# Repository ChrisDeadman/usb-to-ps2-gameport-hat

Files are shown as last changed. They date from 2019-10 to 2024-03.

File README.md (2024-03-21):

Usb => PS/2 & Gameport HAT v1.4
===============================

Author: ChrisDeadman

Convert USB devices to PS/2 & Gameport devices with the power of Arduino 🙂

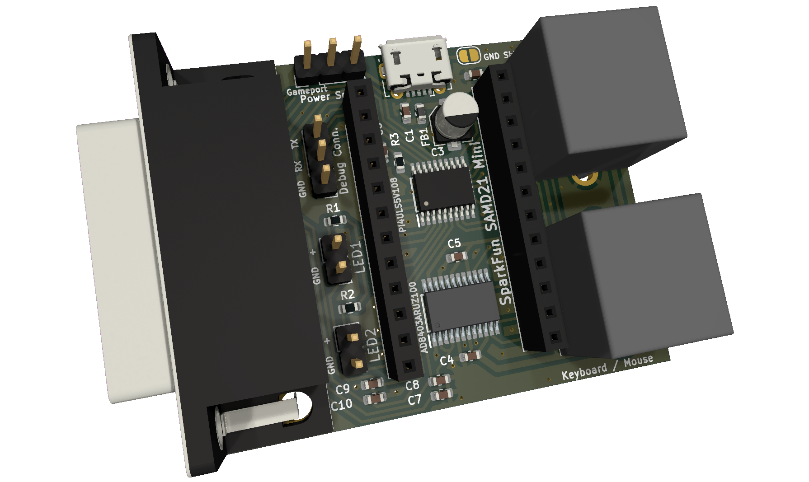
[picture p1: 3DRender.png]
3D render


## Supported input devices
* HID Mouse
* HID Keyboard
* HID Mouse / Keyboard Combo
* HID Joystick / Gamepad\*
* Xbox 360 Controller\*\*

\* *Descriptor parsing is a work in progress and may not work for all devices.*  
\*\* *Currently, only the Xbox 360 Wireless Receiver is supported.*

## Outputs
* PS/2 Mouse\* port
* PS/2 Keyboard\*\* / Mouse combined port
* Gameport

\* *All types are supported, including IntelliMouse (5 Buttons + Scroll wheel).*  
\*\* *Scancode Set 2*

## Supported Arduino Boards
* [SparkFun SAMD21 Mini Breakout](https://www.sparkfun.com/products/13664)\*

\* *Other ATSAMD21G18 boards should also work well, provided they have the same pinout.*

## Usage

* Power the board using a USB cable and set the **Power select** jumper to **USB**.  
  **Alternative:** Set **Power select** jumper to **Gameport**. Be aware that the current is limited depending on the host machine.

* Use a USB OTG cable to connect your USB device to the Arduino.  
  **Recommendation:** Connect a USB hub to the Arduino if you want to use multiple USB devices.

## LEDs

* **LED1** is **ON** if the host inhibits any PS/2 port.
* **LED1** is **FLASHING** if data transfer occurs over any PS/2 port.
* **LED2** indicates **Joy Button** press or the highest **Axis Value**.

## Input Mappings

### USB -> Gameport

This is how USB Joysticks / Gamepads are mapped to the Gameport:

| Joystick 1 | Joystick 2 | Gameport |
|:---|:---|:---|
| X-Axis 1 / D-Pad | - | X-Axis 1 |
| Y-Axis 1 / D-Pad | - | Y-Axis 1 |
| X-Axis 2 | X-Axis 1 / D-Pad  | X-Axis 2 |
| Y-Axis 2 | Y-Axis 2 / D-Pad  | Y-Axis 2 |
| Button 1 / A / R2 | - | Button 1 |
| Button 2 / B / L2 | - | Button 2 |
| Button 3 / X / Select | Button 1 / A / R2 | Button 3 |
| Button 4 / Y / Start  | Button 2 / B / L2 | Button 4 |

### Emulation Mode Mappings

Consult the table below to understand the mapping between various device inputs when an emulation mode is enabled:

| Keyboard | Mouse | Joystick | Gameport |
|:---|:---|:---|:---|
| Left / Right Arrow  | X-Axis | X-Axis 1 / D-Pad | X-Axis 1 |
| Up / Down Arrow | Y-Axis | Y-Axis 1 / D-Pad | Y-Axis 1 |
| A / D | - | X-Axis 2 | X-Axis 2 |
| W / S | Scroll wheel | Y-Axis 2 | Y-Axis 2 |
| L-Ctrl / R-Ctrl | Button 1 | Button 1 / A | Button 1 |
| Space / R-Shift | Button 2 | Button 2 / B | Button 2 |
| L-Alt / CapsLock | Button 3 | Button 3 / X | Button 3 |
| L-Shift | Button 4 | Button 4 / Y | Button 4 |
| Period | Button 5 | Button 5 / R1 | - |
| Comma | - | Button 6 / L1 | - |
| Up Arrow | - | Button 7 / R2 | - |
| Down Arrow | - | Button 8 / L2 | - |
| Escape | - | Button 9 / SELECT | - |
| Tab | - | Button 10 / START | - |

#### Here are a few examples:

* **Joystick -> Keyboard** Emulation Mode:  
  Moving the joystick along X-Axis 1 *(or D-Pad left and right)* acts as if you pressed the Left / Right Arrow keys on the keyboard.

* **Joystick -> Mouse** Emulation Mode:  
  Moving the joystick along X-Axis 1 *(or D-Pad left and right)* move the mouse cursor along the X-Axis.

* **Keyboard -> Joystick** Emulation Mode:  
  If **L-CTRL** or **R-CTRL** is pressed, it acts as if you pressed Button 1 on the joystick.

* **Keyboard -> Mouse** Emulation Mode:  
  The Left / Right Arrow keys on your keyboard move the mouse cursor along the X-Axis.

* **Mouse -> Joystick** Emulation Mode:  
  Moving the mouse left and right corresponds to moving the joystick along the X-Axis 1.

## Setup Mode

Enter this mode to enable special features. Note that those settings are reset to default when the device is reset.

#### Feedback

* **LED1** blink count indicates the current setting.
* **LED2** blink count indicates the value of the current setting, blinks only in edit mode.
* Keyboard LEDs will also blink accordingly (**LED1**=**CapsLock**, **LED2**=**NumLock** and **ScrollLock**).
* LEDs of supported controllers (e.g. Xbox 360) will also blink accordingly.

#### Settings

| Setting | LED1 Blinks | Values / LED2 Blinks | Default |
|:---|:---:|:---|:---:|
| Emulation Mode | 1 | **OFF** | **OFF** |
| | | **1**  Joystick -> Keyboard | |
| | | **2**  Joystick -> Mouse | |
| | | **3**  Keyboard -> Joystick | |
| | | **4**  Keyboard -> Mouse | |
| | | **5**  Mouse -> Joystick | |
| Swap joy axis 3 and 4 | 2 | **ON** / **OFF** | **OFF** |
| Mouse Emu Speed | 3 | **1 <= n <= 255** | **2** |

#### Key bindings

| Keyboard | Joystick / Gamepad | Function |
|:---|:---|:---|
| CTRL+SHIFT+WIN  | Button 5 / R1 + Button 6 / L1 | Hold for ~1s to enter/exit setup mode |
| Return | Button 1 / A | Edit setting / exit edit mode |
| Right Arrow | X-Axis 1 / D-PAD Right | Next setting / increase value (edit mode) |
| Left Arrow | X-Axis 1 / D-PAD Left | Prev. setting / decrease value (edit mode) |
| ESC | Button 9 / SELECT | Apply Default Settings and exit setup mode |
| F1 | - | Set Emulation Mode #1 and exit setup mode |
| F2 | - | Set Emulation Mode #2 and exit setup mode |
| F3 | - | Set Emulation Mode #3 and exit setup mode |
| F4 | - | Set Emulation Mode #4 and exit setup mode |
| F5 | - | Set Emulation Mode #5 and exit setup mode |
| F6 | - | Toggle Swap joy axis 3 and 4 and exit setup mode  |
| F7 | - | Decrease Mouse Emu Speed and exit setup mode |
| F8 | - | Increase Mouse Emu Speed and exit setup mode |

## Flashing the firmware

* Install drivers for you serial adapter
* Connect the **SAMD21 Mini Breakout** to your computer  
*(either via USB OTG cable or via the Debug Conn. pins using a USB<->Serial converter)*
* Double-Tap the reset button on the board to enter bootloader mode

### Automatically

* [Download and run latest firmware_flash.bat](https://github.com/ChrisDeadman/usb-to-ps2-gameport-hat/releases/latest)

### Manually

* [Download latest firmware.bin](https://github.com/ChrisDeadman/usb-to-ps2-gameport-hat/releases/latest)
* [Download Bossa](https://www.shumatech.com/web/products/bossa)
* Flash with `bossac --port=/dev/ttyUSB0 -U -i --offset=0x2000 -e -w firmware.bin -R`

*Ensure you change `--port` to match your system's actual port. The example provided is for Linux systems.*

## Developer Notes

* Diagnostic information is available via **Debug Conn. @ 115200 8N1**  
  *Sending any character returns sent/received data and device status.*

* Enable USB Debugging in `USB.h` *(in USB_Host_Library_SAMD)* by uncommenting `#define DEBUG_USB_HOST 1` and setting `#define USB_HOST_SERIAL` to `SERIAL_PORT_HARDWARE`.

* You can change pins in `include/Config.h`.

* You can add support for additional USB devices by implementing a `JoystickDriverMapper` and adding it to `joy_mappers` in `main.cpp`.

Schematic
=========

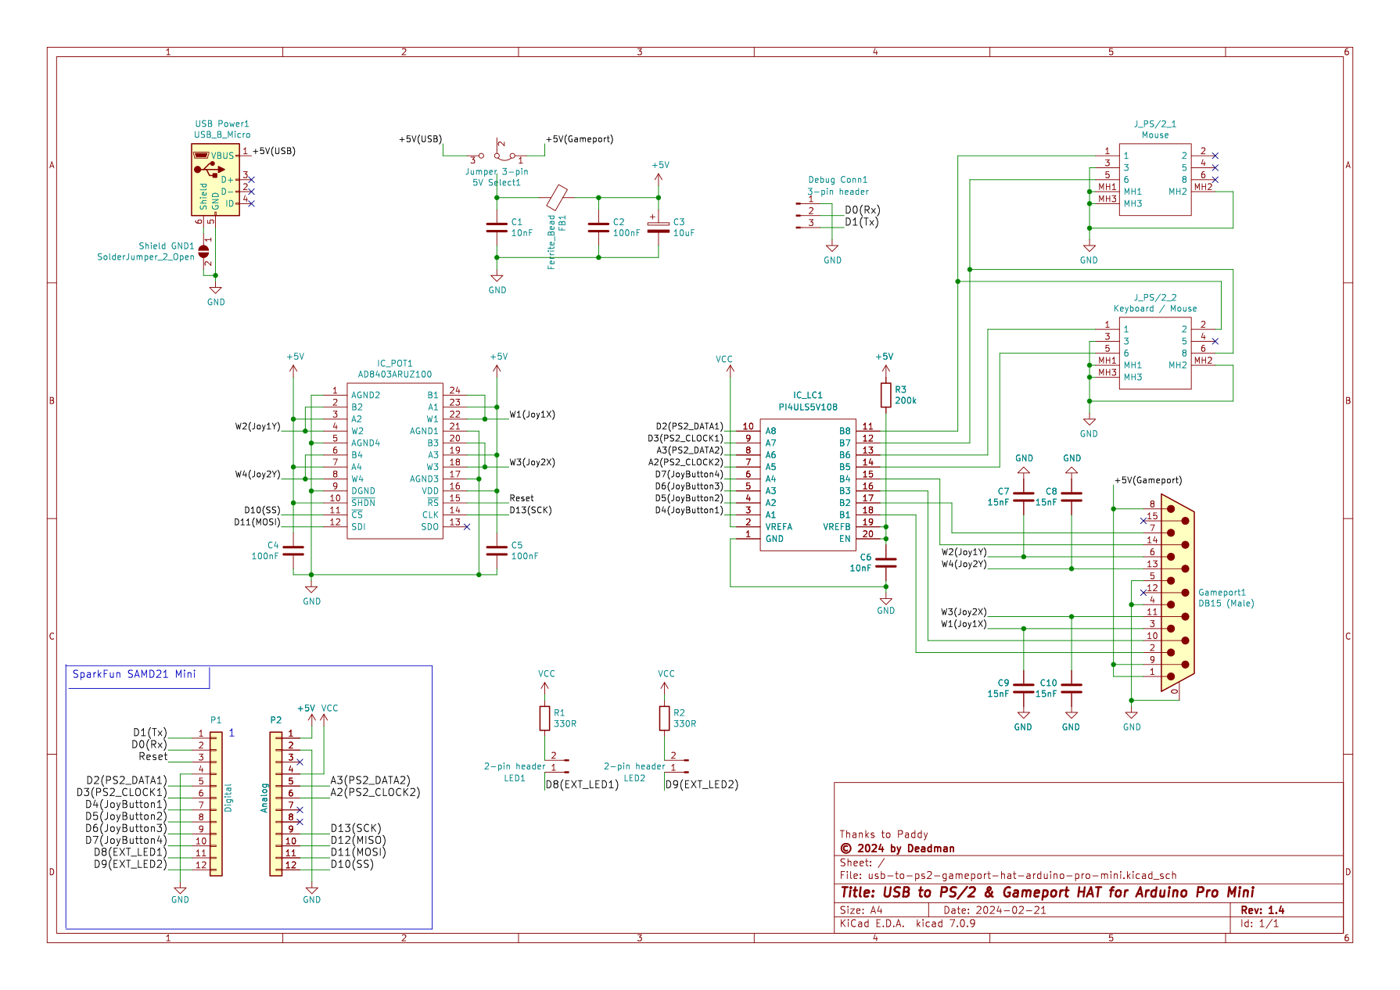
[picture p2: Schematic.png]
Schematic


Layout
======

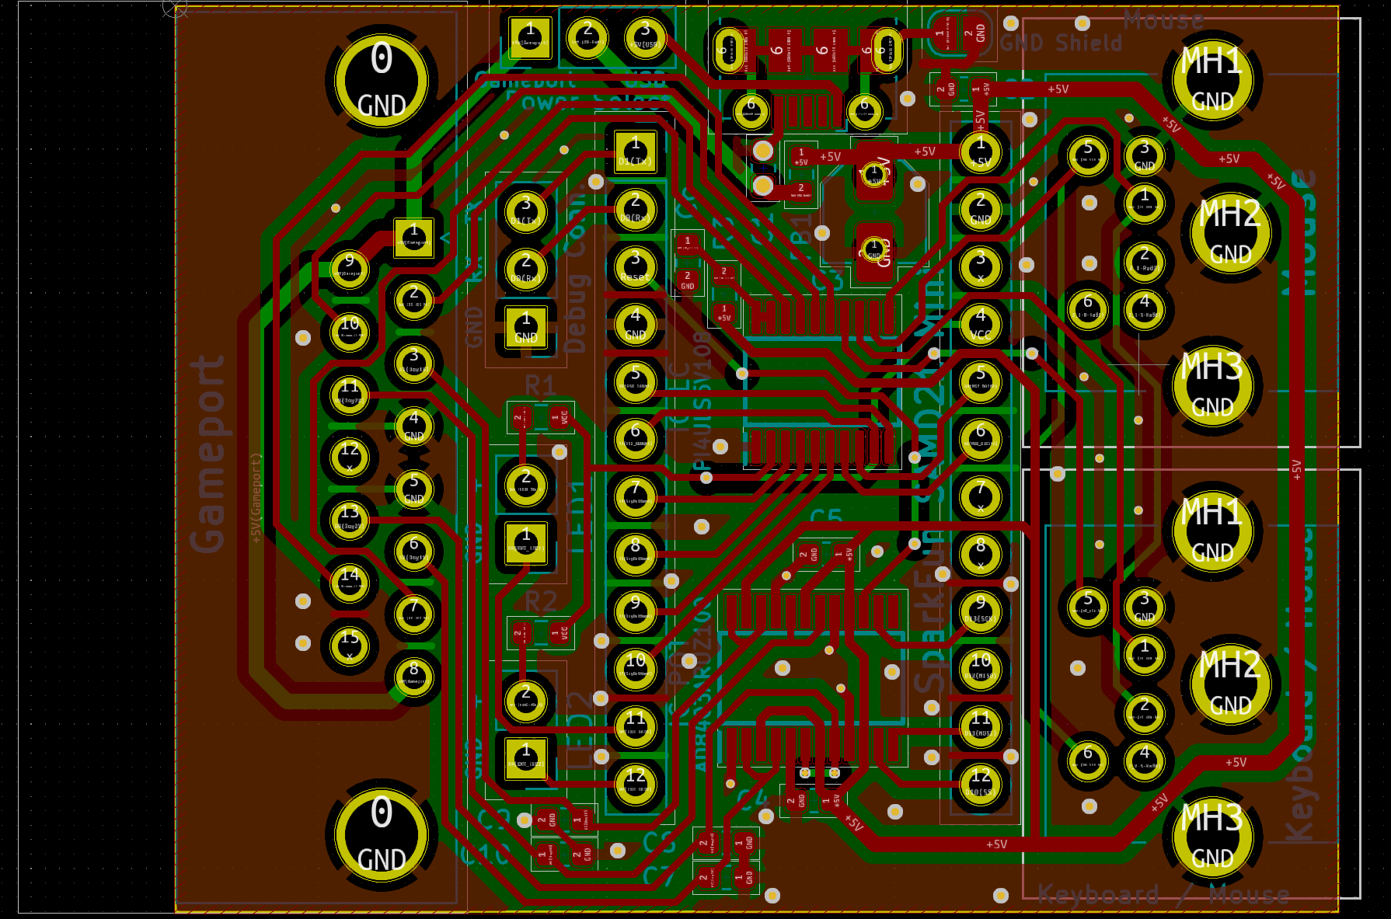
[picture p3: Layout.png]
Layout


Upside
======

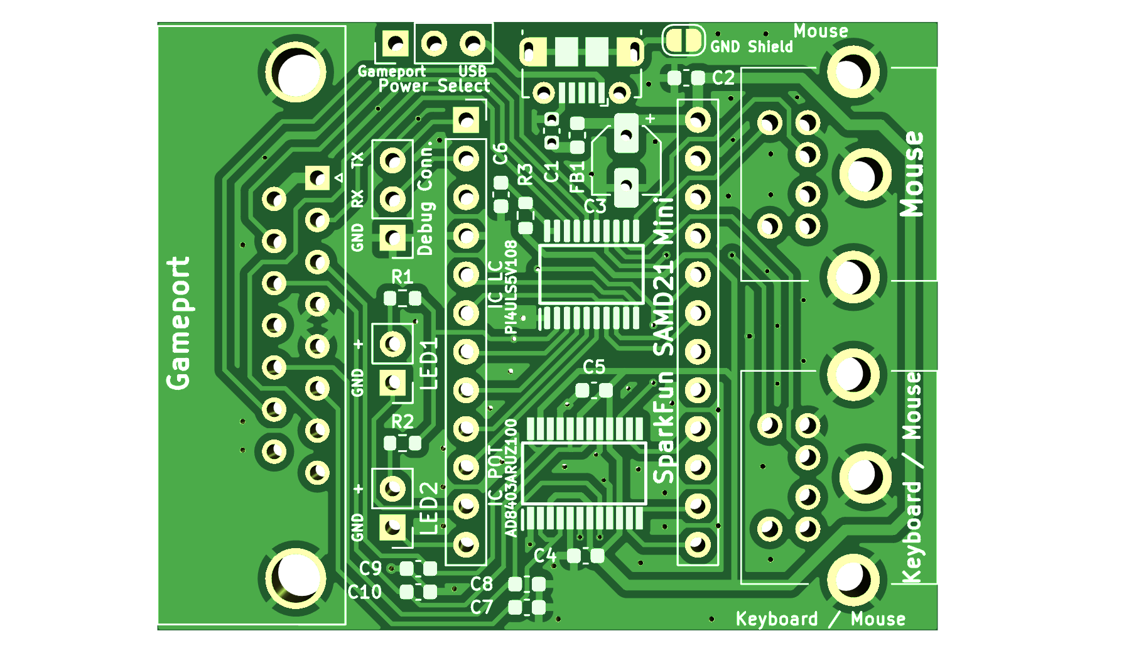
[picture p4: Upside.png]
Upside


Backside
========

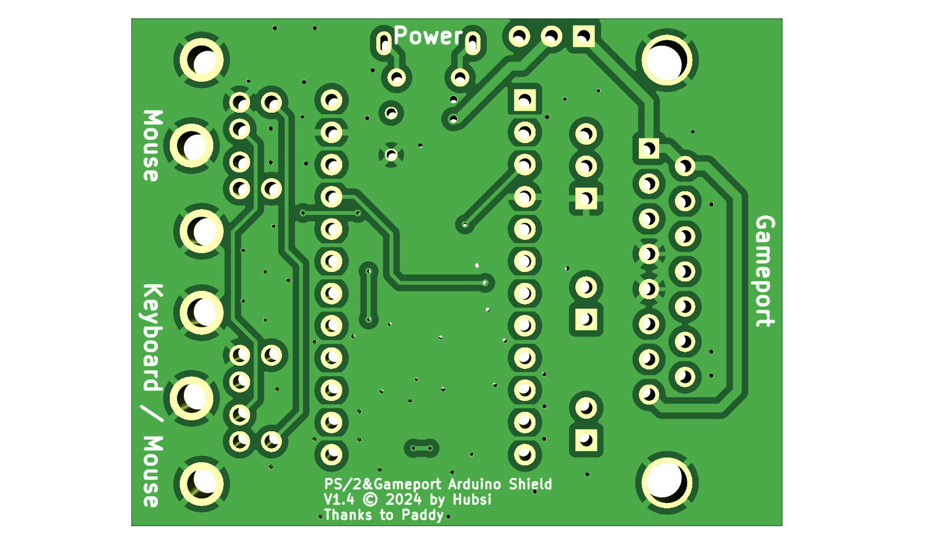
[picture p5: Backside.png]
Backside


Release notes
=============

### Usb => PS/2 & Gameport HAT v1.4
* Add keyboard support
* Add device emulation modes
* @Ulfenknulfen: Fix Joy Axes hardware bug which limited axes range and fixes calibration issues
* Rework and document setup mode
* Rework device input combining
* Always signal inhibited state with LED1
* Improve serial logging

### Usb => PS/2 & Gameport HAT v1.3
* @Ulfenknulfen: Make secondary PS/2 connector a combined connector
* @Ulfenknulfen: PCB layout improvements

### Usb => PS/2 & Gameport HAT v1.2
* Add a second PS/2 port to support keyboards in the future

### Usb => PS/2 & Gameport HAT v1.1
* Fix incorrect PS/2 pin connections

### Usb => PS/2 & Gameport HAT v1.0
* Initial version

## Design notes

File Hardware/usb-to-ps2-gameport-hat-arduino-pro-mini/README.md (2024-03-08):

Usb => PS/2 & Gameport HAT v1.4
===============================

## Where to order which parts?
You can generate a BOM (bill of materials) from within KiCad in order to easily see the parts you need.

I made sure to pick parts with good availability so I could order all of them at once at [Mouser](https://mouser.com).

## Where to order the PCB?
Pretty much all manufacturers should support KiCad or Gerber formats.

I ordered at [EuroCircuits](https://be.eurocircuits.com/) for this project but e.g. [JLCPCB](https://jlcpcb.com/) should also be fine!

## How to generate gerber files?
Pre-generated gerber files are [here](https://github.com/ChrisDeadman/usb-to-ps2-gameport-hat/tree/master/Hardware/usb-to-ps2-gameport-hat-arduino-pro-mini/Gerberfiles_RTU/Gerber_RTU.zip).

Should you want to generate them yourself, you need to install [KiCad](https://kicad-pcb.org/) to open the project and export the gerber files,
[JLCPCB](https://support.jlcpcb.com/article/44-how-to-export-kicad-pcb-to-gerber-files) has a nice tutorial of how to do that.

## How to solder?
If you order a stencil with your PCB you can use a normal oven to solder the stuff in place - in this case I would still solder the "big" elco manually afterwards because of heat concerns.

I did solder everything manually tho using the soldering iron I use for normal prototyping, just make sure to use a lot of flux for the ICs to avoid shorting the pins - and best triple-check afterwards that you didn't 😉

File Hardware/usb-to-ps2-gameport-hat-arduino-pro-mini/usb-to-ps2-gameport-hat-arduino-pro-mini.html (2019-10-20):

# C:\Users\deadman\OneDrive\documents\Projects\usb-to-ps2-gameport-hat-arduino-pro-mini\usb-to-ps2-gameport-hat-arduino-pro-mini.sch

15.08.2019 16:30:47

Eeschema (5.1.4)-1

Component Count:22

Ref | Qnty | Value | Part | Footprint | Description | Vendor
C1, C4 | 2 | 10nF | Device:C | Capacitor_SMD:C_0603_1608Metric | Unpolarized capacitor
C2, C5, C6 | 3 | 100nF | Device:C | Capacitor_SMD:C_0603_1608Metric | Unpolarized capacitor
C3 | 1 | 4.7uF | Device:CP | Capacitor_SMD:CP_Elec_4x5.4 | Polarized capacitor
FB1 | 1 | Ferrite_Bead | Device:Ferrite_Bead | Inductor_SMD:L_0603_1608Metric | Ferrite bead
IC_LC1 | 1 | PI4ULS5V108 | SymacSys_Parts:PI4ULS5V108 | Package_SO:TSSOP-20_4.4x6.5mm_P0.65mm | 8-Bit Bi-directional Level Shifter for Open-Drain and Push-Pull Application
IC_POT1 | 1 | AD8403ARUZ100 | SymacSys_Parts:AD8403ARUZ100 | SamacSys_Parts:SOP65P640X120-24N | AD8403ARUZ100, Digital Potentiometer 100k 256-Position Linear 4-channel Serial-3 Wire, Serial-SPI 24-Pin TSSOP
J_EXT_LED1, J_EXT_LED2 | 2 | 2-pin header | Connector:Conn_01x02_Male | Connector_PinHeader_2.54mm:PinHeader_1x02_P2.54mm_Vertical | Generic connector, single row, 01x02, script generated (kicad-library-utils/schlib/autogen/connector/)
J_GAMEPORT1 | 1 | DB15 (Male) | Connector:DB15_Male_MountingHoles | Connector_Dsub:DSUB-15_Male_Horizontal_P2.77x2.84mm_EdgePinOffset4.94mm_Housed_MountingHolesOffset7.48mm | 15-pin male D-SUB connector (low-density/2 columns), Mounting Hole
J_PS/2 | 1 | KMDGX-6S-BS | SymacSys_Parts:KMDGX-6S-BS | SamacSys_Parts:KMDGX6SBS | Circular DIN Connectors 6P R/A FULL SHIELD GOLD PLANTED
J_SER1 | 1 | 3-pin header | Connector:Conn_01x03_Male | Connector_PinHeader_2.54mm:PinHeader_1x03_P2.54mm_Vertical | Generic connector, single row, 01x03, script generated (kicad-library-utils/schlib/autogen/connector/)
J_USB_PWR1 | 1 | USB_B_Micro | Connector:USB_B_Micro | Connector_USB:USB_Micro-B_Molex-105017-0001 | USB Micro Type B connector
JP_5V_SEL1 | 1 | Jumper 3-pin | Jumper:Jumper_3_Bridged12 | Connector_PinHeader_2.54mm:PinHeader_1x03_P2.54mm_Vertical | Jumper, 3-pole, pins 1+2 closed/bridged
JP_SHIELD1 | 1 | SolderJumper_2_Open | Jumper:SolderJumper_2_Open | Resistor_SMD:R_0402_1005Metric | Solder Jumper, 2-pole, open
P1 | 1 | Digital | Connector_Generic:Conn_01x12 | Socket_Arduino_Pro_Mini:Socket_Strip_Arduino_1x12 | Generic connector, single row, 01x12, script generated (kicad-library-utils/schlib/autogen/connector/)
P2 | 1 | Analog | Connector_Generic:Conn_01x12 | Socket_Arduino_Pro_Mini:Socket_Strip_Arduino_1x12 | Generic connector, single row, 01x12, script generated (kicad-library-utils/schlib/autogen/connector/)
R1, R2 | 2 | 330R | Device:R | Resistor_SMD:R_0603_1608Metric | Resistor
R3 | 1 | 200k | Device:R | Resistor_SMD:R_0603_1608Metric | Resistor

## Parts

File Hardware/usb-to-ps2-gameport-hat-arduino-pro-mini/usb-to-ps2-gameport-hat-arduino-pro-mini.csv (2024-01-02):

ID | Bezeichner | Footprint | Stückzahl | Bezeichnung | Anbieter und Referenz
1 | C2,C4,C5 | C_0603_1608Metric | 3 | 100nF
2 | P2 | PinSocket_1x12_P2.54mm_Vertical | 1 | Analog
3 | Debug Conn1 | PinHeader_1x03_P2.54mm_Vertical | 1 | 3-pin header
4 | P1 | PinSocket_1x12_P2.54mm_Vertical | 1 | Digital
5 | IC_POT1 | SOP65P640X120-24N | 1 | AD8403ARUZ100
6 | C1,C6 | C_0603_1608Metric | 2 | 10nF
7 | C3 | CP_Elec_4x5.4 | 1 | 10uF
8 | R2,R1 | R_0603_1608Metric | 2 | 330R
9 | IC_LC1 | TSSOP-20_4.4x6.5mm_P0.65mm | 1 | PI4ULS5V108
10 | Gameport1 | DSUB-15_Male_Horizontal_P2.77x2.84mm_EdgePinOffset7.70mm_Housed_MountingHolesOffset9.12mm | 1 | DB15 (Male)
11 | C8,C10,C7,C9 | C_0603_1608Metric | 4 | 15nF
12 | USB Power1 | USB_Micro-B_Molex-105017-0001 | 1 | USB_B_Micro
13 | FB1 | L_0603_1608Metric | 1 | Ferrite_Bead
14 | Shield GND1 | SolderJumper-2_P1.3mm_Open_RoundedPad1.0x1.5mm | 1 | SolderJumper_2_Open
15 | 5V Select1 | PinHeader_1x03_P2.54mm_Vertical | 1 | Jumper 3-pin
16 | J_PS/2_2 | KMDGX6SBS | 1 | Keyboard / Mouse
17 | , |  | 2
18 | LED1,LED2 | PinHeader_1x02_P2.54mm_Vertical | 2 | 2-pin header
19 | J_PS/2_1 | KMDGX6SBS | 1 | Mouse
20 | R3 | R_0603_1608Metric | 1 | 200k

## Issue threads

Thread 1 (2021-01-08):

Atari clone with ps/2

ps68060, 2021-01-08:
I am a newcomer to Arduino but I have been looking for a way to connect USB mouse (wireless) to an Atari clone that has ps/2 sockets only. https://uweschneider.de/en/projects_milan.php

I found your archived project https://github.com/ChrisDeadman/Usb2Ps2Mouse  which looks ideal but then I saw this project and wondered if it is the better solution.

Hardware is not my area so I want to keep that to a minimum.

ChrisDeadman, 2021-01-30:
Hi!
The mouse code of both projects should be pretty equal, I rechecked and do not see that I had to fixed anything afterwards.
You can use either but I would recommend this project (you do not need to use the PCB from this project, it is only needed for gameport support and has the PS/2 connector soldered)
You can change the pins for the PS/2 output in https://github.com/ChrisDeadman/usb-to-ps2-gameport-hat/blob/master/Software/usb-to-ps2-gameport-hat/include/Config.h

ChrisDeadman, 2021-01-30:
fyi: make sure to use a level-converter from 3.3V to 5V for the PS/2 connector like in the picture of the Usb2Ps2Mouse, I ordered those and they work well for prototyping https://www.amazon.de/gp/product/B07F3P942R

Closed 2022-02-04.

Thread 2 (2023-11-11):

Keyboard Support Feature Request

Ulfenknulfen, 2023-11-11:
Hi Chris. That's a super amazing Project for Retro-PC's!

Is Keyboard support comming in the next time?

best regards
Paddy

ChrisDeadman, 2023-11-29:
Hey @Ulfenknulfen!

Thanks for your interest in the project!
Keyboard support really is something I wanted to add for years now but unfortunately I haven't had much time lately for my retro projects :disappointed:
If I ever get back to it I will add it but that won't be in the near future :/

In case someone else wants to contribute I should find time tho to review pull requests and give some pointers.

DaveSmith1985, 2023-12-18:
With Keyboard Support (for logitech usb that have keyb and mouse...) this project will be awesome!

Ulfenknulfen, 2023-12-18:
Hi Dave and Chris.

Yes this IS an awesome Project for every Retro-PC. But i think there's a small mistake in kicad Project...
PS/2 Pin 4 must be 5V, i think.

[kicad.zip](https://github.com/ChrisDeadman/usb-to-ps2-gameport-hat/files/13706782/kicad.zip)

best regards
Paddy

ChrisDeadman, 2023-12-19:
Damn, how could I miss that - actually not that small of a mistake 😆
Seems the mouse I used for testing powered itself over the data line 😀
In your zip it's fixed for the PCB but not in the schematic, I will fix it in the schematic as well then push fix.
Thanks for finding it!

Ulfenknulfen, 2023-12-20:
No Problem.

you can also checkout and use my new kicad file - i did some
improvements.

best regards and have a nice X-Mas :-)
Paddy

[kicad.zip](https://github.com/ChrisDeadman/usb-to-ps2-gameport-hat/files/13725405/kicad.zip)

Ulfenknulfen, 2023-12-20:
Hi Chris.

It has nothing to do with USB Functionality. It's just for deliver 5V to the Circuit.
Some users have no Gameport, and want just use it for Keyboard/Mouse... .

best regards
Paddy

Feel free to use the files!
[Kicad.zip](https://github.com/ChrisDeadman/usb-to-ps2-gameport-hat/files/13726004/Kicad.zip)

ChrisDeadman, 2023-12-20:
Yeah sorry, it was a bit late yesterday 😂 I have to revert my statement because this is the connection to the PC and the PS/2 cannot really deliver enough current that is why I did not connect it initially.
The intention was that you either get power from Gameport (which is not recommended since it can also not deliver much current) or via USB. That is why there is a USB connector on the board, it's purely for power-delivery.

Ulfenknulfen, 2023-12-20:
Hi Chris.

Yes, that makes perfect sense, of course!
I don't want to be annoying, but is there anything new about Keyboard support?

best regards
Paddy

Ulfenknulfen, 2023-12-20:
I Order PCB too, but i dont need all 5 of them.

Where are you from? Germany?

Best regards

Paddy

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

Ulfenknulfen, 2023-12-20:
I will Order PCB's too, but i don't need all 5 of them.

Where are you from? Germany?

Best regards

Paddy
P.S. i did some optimisations. Here the actual Files:
[Kicad.zip](https://github.com/ChrisDeadman/usb-to-ps2-gameport-hat/files/13730765/Kicad.zip)

ChrisDeadman, 2023-12-20:
I will have a look next week to compare the changes.
Btw. it would help a lot if you fork the project it and make pull request if you have time at some point, so much easier to compare changes and comment instead of just this issue.

Thanks for your contribution, it means a lot because I really didn't have much time and I really appreciate if this project is finally used by someone else than just me 🙂
I'm from Austria, so not too far apart, my mail is christopher.hubmann@gmail.com, let's get in contact, I would pay for the shipping and some of the PCB cost then 🙂

Ulfenknulfen, 2023-12-23:
i did ;-)

best regards
paddy

ChrisDeadman, 2024-01-22:
Thanks @Ulfenknulfen for your help with this Pull Request!
After some testing we now have a good initial version I would say 🙂

Ulfenknulfen, 2024-01-22:
It was a honor to work on this Project!

best reagrds
Paddy

Closed 2024-01-22.

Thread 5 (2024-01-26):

USB Issues

ChrisDeadman, 2024-01-26:
Often times Hotplug is not working, other times it doesn't detect devices at boot-up but only after hotplug and then sometimes it doesn't detect them them at all.

The plan is to switch the complete USB stack to [tinyusb](https://docs.tinyusb.org/en/latest/).

ChrisDeadman, 2024-02-04:
Unfortunately, tinyusb does not support SAMD in host mode yet but it should be possible to add it.

ChrisDeadman, 2024-03-09:
Update: I've implemented support for SAMD21 host mode here: https://github.com/ChrisDeadman/tinyusb/tree/hcd-samd-support

Next step: Integrate into this project and rewrite USB drivers

ChrisDeadman, 2024-10-20:
More important step before that: Get everything working for most people with the current thing.

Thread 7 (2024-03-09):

USB 1.1 Keyboards do not work if connected via USB HUB

ChrisDeadman, 2024-03-09:
At least for my USB 1.1 Keyboard that is the case.
It seems to be a quirk of the SAMD21 since my TinyUSB port has the same issues even if I wrote it from scratch using interrupts and just the datasheet.

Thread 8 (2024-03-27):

Not an Issue!

MichaelKoch1980, 2024-03-27:
Hi Developers.

I saw your project on Vogons, and ordered the dividers directly
from Digikey, PCBway.
Now everything is ready and works perfectly!
I'm really excited! I use Logitech mouse and keyboard, and the
XBOX 360 controller :-).
It's a lot of fun, especially the Doom mode!

thank you, Guys!

Michael

ChrisDeadman, 2024-03-28:
Great to hear Michael! Have fun 😁

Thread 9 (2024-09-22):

DOS Mouse Problem

DaveSmith1985, 2024-09-22:
Hi dear Deadman.

In Win9x the Adaptor is working fine, but in dos the Mouse cursor springs in the
lower left corner, and nothin happens. Testet with different Mousedrivers, and the issue
is also under win3.11 :-(

ChrisDeadman, 2024-10-03:
Hey Dave, thanks for the bug report!
I've heard about this already from another user, but could not reproduce it myself on my machines :/

Do you by any chance have the option to connect a 3.3V serial adapter to the 3-pin debug connector?
If you connect there using 115200 baud and send any keypress (e.g. ENTER), it prints the last received and transmitted packets.
That would enable me to trace the issue.

ChrisDeadman, 2024-10-12:
I've found a potential issue when going through the code, could you try this firmware and see if that fixes it?
[firmware.bin.zip](https://github.com/user-attachments/files/17350968/firmware.bin.zip)

ChrisDeadman, 2024-10-19:
@Ulfenknulfen and me have looked into that issue further, and with regards to the stuff that is transferred over PS/2 on his machine, I cannot find an issue.
I've modified the firmware.bin in the above comment to the one I think might fix incompatibility issues with some boards, but it did not fix the mouse issues for @Ulfenknulfen unfortunately 🫤
@DaveSmith1985 Could you tell me what motherboard you are using?

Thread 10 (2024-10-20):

"Bouncy" Keyboard on some PCs

ChrisDeadman, 2024-10-20:
**Describe the bug**
On some PCs, using basically any keyboard, repetition of keys may be observed - keys may feel "bouncy" so to speak.

**Steps To Reproduce**
- Have a controller that requires discipline
- Connect my creation and try to type as normal

**Expected behavior**
It should just work.

**Actual behavior**
It sucks.

ChrisDeadman, 2024-10-20:
Might be fixed with this, @Ulfenknulfen is currently trying it out.

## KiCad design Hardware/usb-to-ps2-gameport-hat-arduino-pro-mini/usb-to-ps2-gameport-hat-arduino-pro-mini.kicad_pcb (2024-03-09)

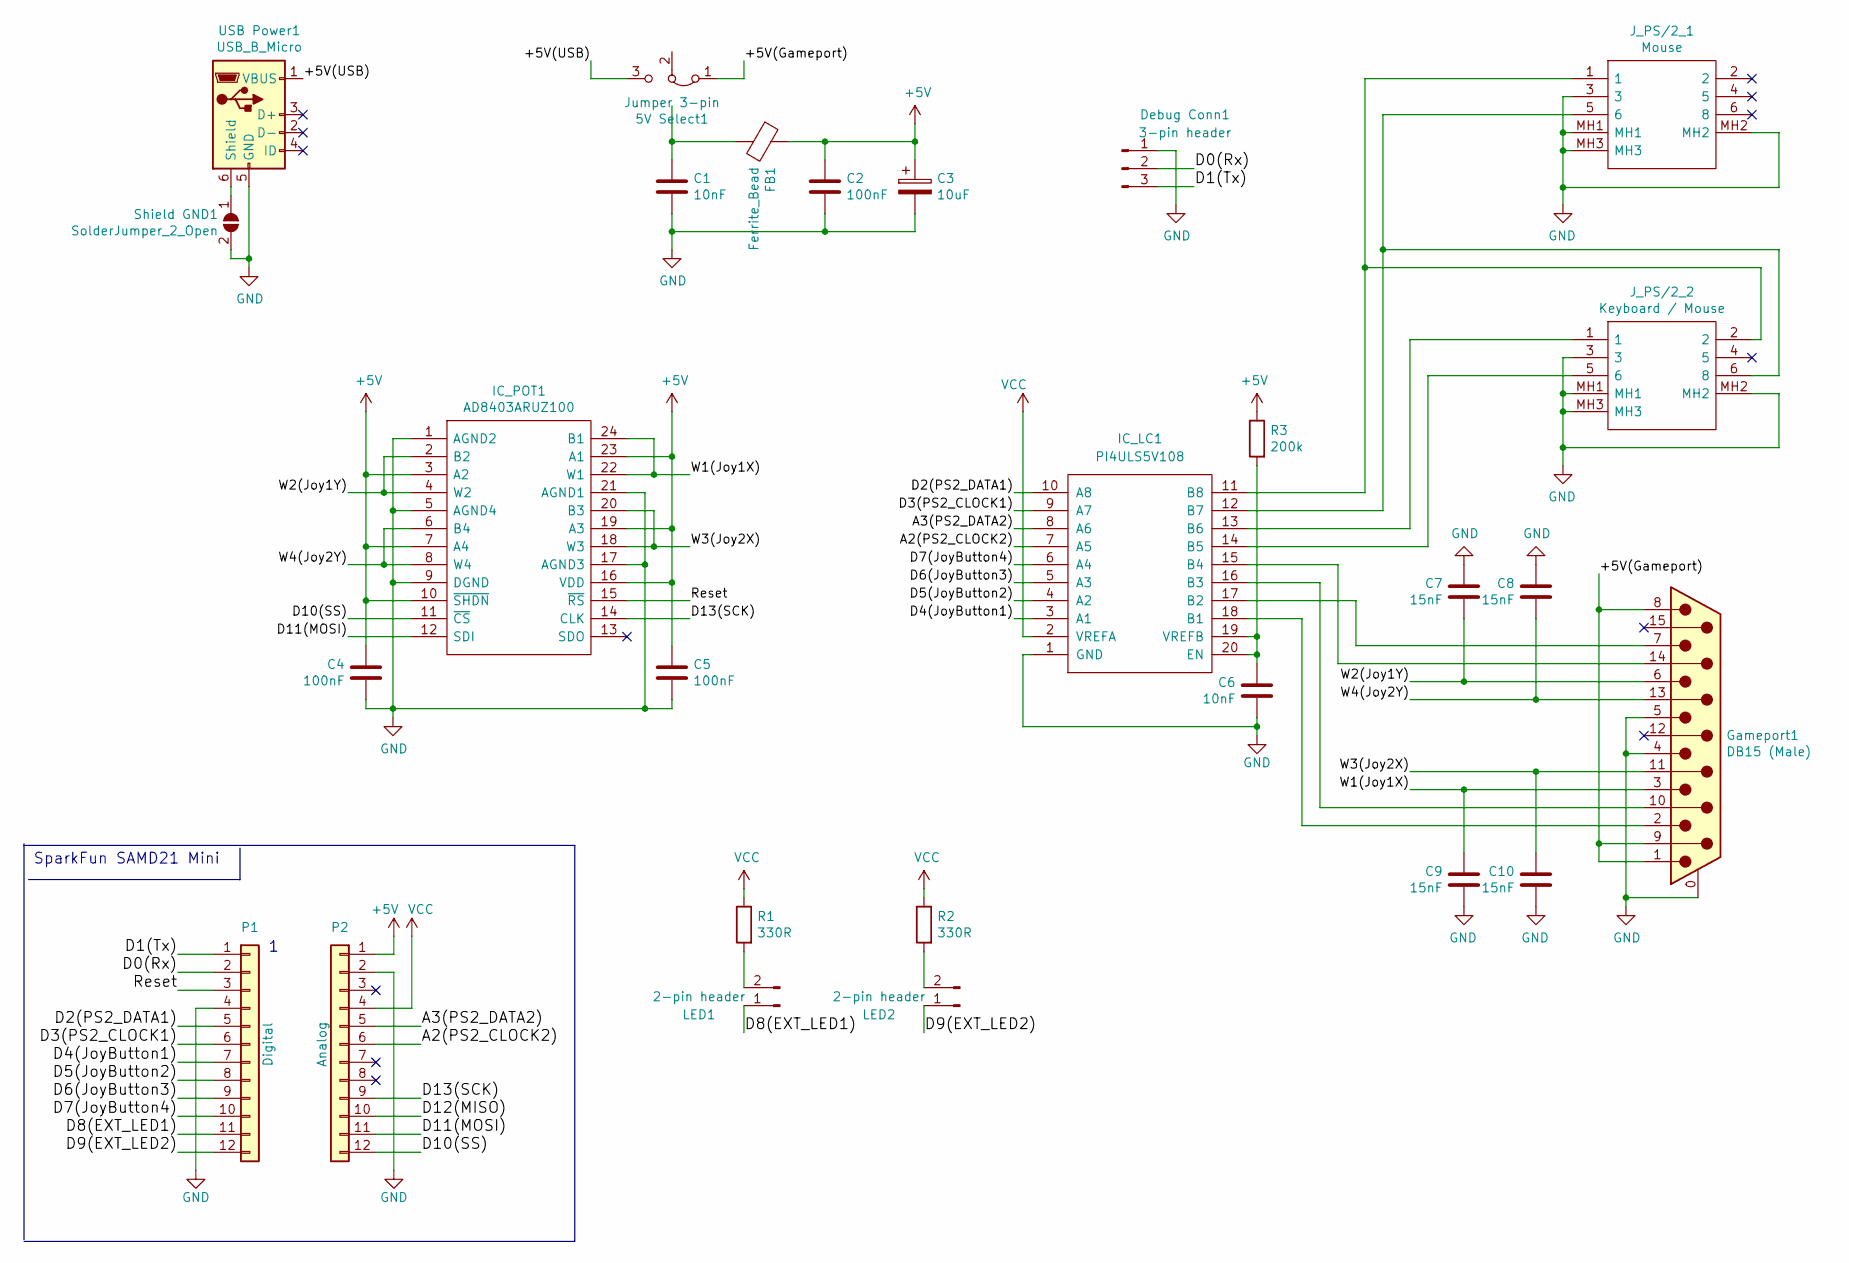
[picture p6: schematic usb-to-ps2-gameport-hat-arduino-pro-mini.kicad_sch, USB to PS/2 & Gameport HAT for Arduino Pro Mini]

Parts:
5V Select1: Jumper 3-pin; PinHeader_1x03_P2.54mm_Vertical
C1, C6: 10nF; C_0603_1608Metric
C2, C4, C5: 100nF; C_0603_1608Metric
C3: 10uF; CP_Elec_4x5.4
C7, C8, C9, C10: 15nF; C_0603_1608Metric
Debug Conn1: 3-pin header; PinHeader_1x03_P2.54mm_Vertical
FB1: Ferrite_Bead; L_0603_1608Metric
Gameport1: DB15 (Male); DSUB-15_Male_Horizontal_P2.77x2.84mm_EdgePinOffset7.70mm_Ho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
IC_LC1: PI4ULS5V108; TSSOP-20_4.4x6.5mm_P0.65mm
IC_POT1: AD8403ARUZ100; SOP65P640X120-24N; Mouser Part Number 584-AD8403ARUZ100
J_PS/2_1: Mouse; KMDGX6SBS; Mouser Part Number 806-KMDGX-6S-BS
J_PS/2_2: Keyboard / Mouse; KMDGX6SBS; Mouser Part Number 806-KMDGX-6S-BS
LED1, LED2: 2-pin header; PinHeader_1x02_P2.54mm_Vertical
P1: Digital; PinSocket_1x12_P2.54mm_Vertical
P2: Analog; PinSocket_1x12_P2.54mm_Vertical
R1, R2: 330R; R_0603_1608Metric
R3: 200k; R_0603_1608Metric
Shield GND1: SolderJumper_2_Open; SolderJumper-2_P1.3mm_Open_RoundedPad1.0x1.5mm
USB Power1: USB_B_Micro; USB_Micro-B_Molex-105017-0001

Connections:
+5V: C2.1, C3.1, C4.1, C5.1, FB1.1, IC_POT1.3 (A2), IC_POT1.7 (A4), IC_POT1.10 (~SHDN), IC_POT1.16 (VDD), IC_POT1.19 (A3), IC_POT1.23 (A1), P2.1, R3.1
/+5V(Gameport): 5V Select1.1 (A), Gameport1.1, Gameport1.8, Gameport1.9
/+5V(USB): 5V Select1.3 (B), USB Power1.1 (VBUS)
/A2(PS2_CLOCK2): IC_LC1.7 (A5), P2.6
/A3(PS2_DATA2): IC_LC1.8 (A6), P2.5
/D0(Rx): Debug Conn1.2, P1.2
/D1(Tx): Debug Conn1.3, P1.1
/D2(PS2_DATA1): IC_LC1.10 (A8), P1.5
/D3(PS2_CLOCK1): IC_LC1.9 (A7), P1.6
/D4(JoyButton1): IC_LC1.3 (A1), P1.7
/D5(JoyButton2): IC_LC1.4 (A2), P1.8
/D6(JoyButton3): IC_LC1.5 (A3), P1.9
/D7(JoyButton4): IC_LC1.6 (A4), P1.10
/D8(EXT_LED1): LED1.1, P1.11
/D9(EXT_LED2): LED2.1, P1.12
/D10(SS): IC_POT1.11 (~CS), P2.12
/D11(MOSI): IC_POT1.12 (SDI), P2.11
/D12(MISO): P2.10
/D13(SCK): IC_POT1.14 (CLK), P2.9
/Reset: IC_POT1.15 (~RS), P1.3
/W1(Joy1X): C9.1, Gameport1.3, IC_POT1.22 (W1), IC_POT1.24 (B1)
/W2(Joy1Y): C7.2, Gameport1.6, IC_POT1.2 (B2), IC_POT1.4 (W2)
/W3(Joy2X): C10.1, Gameport1.11 (P111), IC_POT1.18 (W3), IC_POT1.20 (B3)
/W4(Joy2Y): C8.2, Gameport1.13, IC_POT1.6 (B4), IC_POT1.8 (W4)
GND: C1.2, C2.2, C3.2, C4.2, C5.2, C6.2, C7.1, C8.1, C9.2, C10.2, Debug Conn1.1, Gameport1.0 (PAD), Gameport1.4, Gameport1.5, IC_LC1.1 (GND), IC_POT1.1 (AGND2), IC_POT1.5 (AGND4), IC_POT1.9 (DGND), IC_POT1.17 (AGND3), IC_POT1.21 (AGND1), J_PS/2_1.3, J_PS/2_1.MH1, J_PS/2_1.MH2, J_PS/2_1.MH3, J_PS/2_2.3, J_PS/2_2.MH1, J_PS/2_2.MH2, J_PS/2_2.MH3, P1.4, P2.2, Shield GND1.2 (B), USB Power1.5 (GND)
unnamed: Gameport1.10, IC_LC1.16 (B3)
unnamed: Gameport1.14, IC_LC1.15 (B4)
unnamed: Gameport1.2, IC_LC1.18 (B1)
unnamed: Gameport1.7, IC_LC1.17 (B2)
unnamed: IC_LC1.14 (B5), J_PS/2_2.5 (6)
unnamed: IC_LC1.13 (B6), J_PS/2_2.1
unnamed: IC_LC1.12 (B7), J_PS/2_1.5 (6), J_PS/2_2.6 (8)
unnamed: IC_LC1.11 (B8), J_PS/2_1.1, J_PS/2_2.2
unnamed: C6.1, IC_LC1.19 (VREFB), IC_LC1.20 (EN), R3.2
unnamed: LED1.2, R1.2
unnamed: LED2.2, R2.2
unnamed: Shield GND1.1 (A), USB Power1.6 (Shield)
VCC: IC_LC1.2 (VREFA), P2.4, R1.1, R2.1

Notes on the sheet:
SparkFun SAMD21 Mini

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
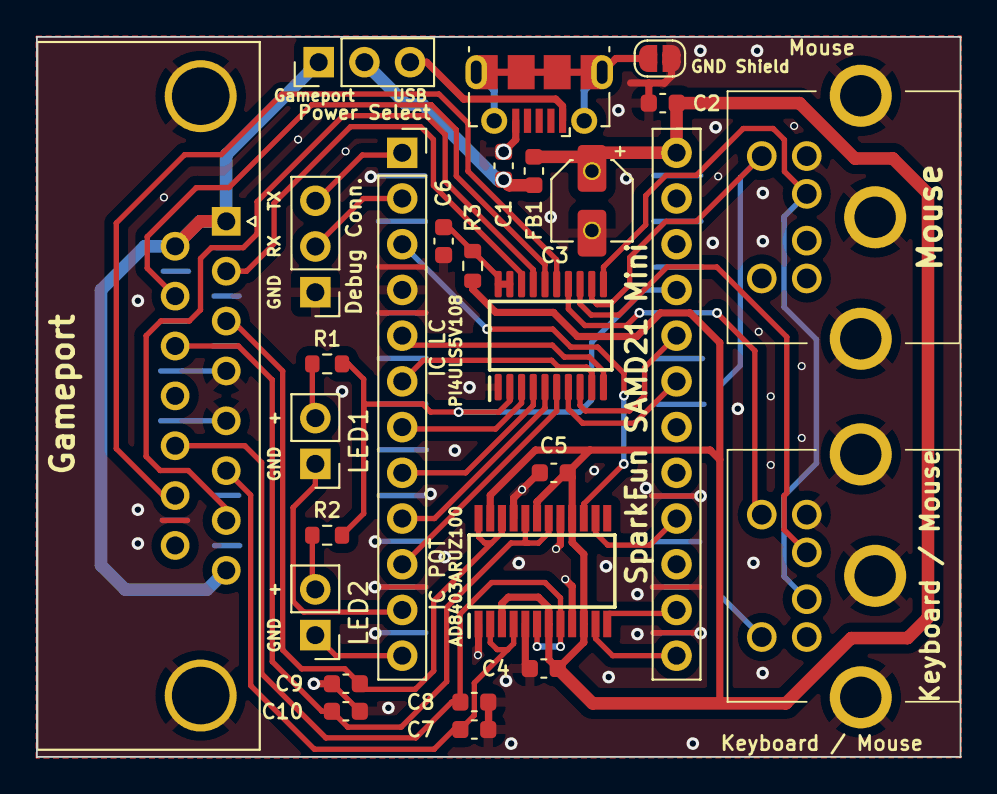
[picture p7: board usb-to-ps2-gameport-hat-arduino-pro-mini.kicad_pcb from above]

Board: 2 copper layers, 51.3 x 40.0 mm, 27 parts (0 on the bottom side), 38 nets.

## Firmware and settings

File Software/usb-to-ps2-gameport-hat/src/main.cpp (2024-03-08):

#include <Arduino.h>

#include "Config.h"
#include "SoftPWM.h"
SoftPWM soft_pwm;

#include "Watchdog.h"
Watchdog watchdog;

#include <Usb.h>
#include <usbhub.h>

#include "HIDMouseKeyboardController.h"
USBHost usb;
USBHub usb_hub(&usb);  // so we can support controllers connected via hubs
HIDBoot<HID_PROTOCOL_MOUSE | HID_PROTOCOL_KEYBOARD> hid_mouse_keyboard_driver(&usb);
HIDMouseKeyboardController usb_mouse_keyboard(&hid_mouse_keyboard_driver);
HIDBoot<HID_PROTOCOL_MOUSE> hid_mouse_driver(&usb);
HIDMouseController usb_mouse(&hid_mouse_driver);
HIDBoot<HID_PROTOCOL_KEYBOARD> hid_keyboard_driver(&usb);
HIDKeyboardController usb_keyboard(&hid_keyboard_driver);

#include <XBOXRECV.h>

#include "HIDJoystickController.h"
#include "HIDJoystickControllerMapper.h"
#include "XBOXRECVMapper.h"
// Joystick drivers
XBOXRECV xbox_recv(&usb);
HIDJoystickController hid_joy_controller_1(&usb);
HIDJoystickController hid_joy_controller_2(&usb);
// Joystick mappers
XBOXRECVMapper xbox_recv_mapper(&xbox_recv);
HIDJoystickControllerMapper hid_joy_controller_1_mapper(&hid_joy_controller_1);
HIDJoystickControllerMapper hid_joy_controller_2_mapper(&hid_joy_controller_2);
IJoystickDriverMapper* joy_mappers[] = {
    &xbox_recv_mapper,
    &hid_joy_controller_1_mapper,
    &hid_joy_controller_2_mapper,
};
const uint8_t num_joy_mappers = sizeof(joy_mappers) / sizeof(IJoystickDriverMapper*);

#include "PS2Keyboard.h"
#include "PS2Mouse.h"
#include "PS2Port.h"
PS2Port ps2_keyboard_port(PS2_2_CLOCK_PIN, PS2_2_DATA_PIN);
PS2Keyboard ps2_keyboard(&ps2_keyboard_port);
PS2Port ps2_mouse_port(PS2_1_CLOCK_PIN, PS2_1_DATA_PIN);
PS2Mouse ps2_mouse(&ps2_mouse_port);
MouseState ps2_mouse_state;

#include "Gameport.h"
Gameport gameport(POT1_CS_PIN, JOY_BUTTON1_PIN, JOY_BUTTON2_PIN, JOY_BUTTON3_PIN, JOY_BUTTON4_PIN);

#include "VirtualJoystick.h"
#include "VirtualKeyboard.h"
#include "VirtualMouse.h"
// Virtual Devices
VirtualKeyboard virtual_keyboard;
VirtualMouse virtual_mouse;
VirtualJoystick virtual_joystick;
MouseState mouse_state;
JoystickState joy_state;
uint8_t num_joys_connected = 0;

#include "SetupMode.h"
SetupMode setup_mode(&virtual_keyboard, &joy_state);

#include "Logging.h"
Logging logging(&usb_mouse_keyboard,
                &usb_keyboard,
                &usb_mouse,
                &mouse_state,
                &joy_state,
                &num_joys_connected,
                &ps2_keyboard,
                &ps2_mouse,
                &setup_mode);

#include "SoftTimer.h"
SoftTimer led_timer;

static void sync_usb_keyboard_state();
static void sync_usb_mouse_state();
static void sync_usb_joystick_state();

static void sync_ps2_keyboard_state();
static void sync_ps2_mouse_state();
static void sync_gameport_state();

#include "DeviceEmulation.h"
static void handle_device_emulation();

static void update_debug_led_state();

void setup() {
  digitalWrite(EXT_LED1_PIN, HIGH);
  digitalWrite(EXT_LED2_PIN, HIGH);
  pinMode(EXT_LED1_PIN, OUTPUT);
  pinMode(EXT_LED2_PIN, OUTPUT);
  logging.init();
  usb.Init();
  ps2_keyboard.init();
  ps2_mouse.init();
  PS2Port::init();
  gameport.init();
  watchdog.init();
  ps2_keyboard.reset();
  ps2_mouse.reset();
}

void loop() {
  // update timers
  watchdog.reset();
  led_timer.tick();

  // handle PS/2 tasks
  ps2_keyboard.task();
  ps2_mouse.task();

  // check if PS/2 is busy
  bool ps2_busy = ps2_keyboard.is_busy() || ps2_mouse.is_busy();

  // Only if PS/2 is not busy
  if (!ps2_busy) {
    // NOTE: lower USB_XFER_TIMEOUT (e.g. to 1000) in UsbCore.h,
    // otherwise this may take longer than the watchdog timeout.
    usb.Task();

    // synchronize input devices
    sync_usb_keyboard_state();
    sync_usb_mouse_state();
    sync_usb_joystick_state();

    // handle device emulation
    if (!setup_mode.in_setup_mode) {
      handle_device_emulation();
    }

    // get input states
    mouse_state = virtual_mouse.pop_state();
    joy_state = virtual_joystick.pop_state();
  }

  // handle setup mode
  setup_mode.task();

  // synchronize output devices
  sync_ps2_keyboard_state();
  sync_ps2_mouse_state();
  sync_gameport_state();

  // don't update LEDs too frequently
  if (led_timer.getElapsedMillis() > LED_UPDATE_INTERVAL) {
    if (!setup_mode.in_setup_mode) {
      // update debug LED state if not in setup mode
      update_debug_led_state();
    }
    led_timer.reset();
  }

  // handle logging
  logging.task();
}

static void sync_usb_keyboard_state() {
  while (true) {
    KeyboardAction kb_action = usb_keyboard.deq();
    if (kb_action.type == KbActionNone) {
      kb_action = usb_mouse_keyboard.deq();
      if (kb_action.type == KbActionNone) {
        break;
      }
    }
    virtual_keyboard.enq(kb_action);
  }

  virtual_keyboard.pop_modifier_state();
  virtual_keyboard.update_modifier_state(usb_keyboard.get_modifier_state());
  virtual_keyboard.update_modifier_state(usb_mouse_keyboard.get_modifier_state());

  if (led_timer.getElapsedMillis() > LED_UPDATE_INTERVAL) {
    KeyboardLeds led_state = virtual_keyboard.get_led_state();
    usb_keyboard.set_led_state(led_state);
    usb_mouse_keyboard.set_led_state(led_state);
  }
}

static void sync_usb_mouse_state() {
  MouseState device_state;

  device_state = usb_mouse_keyboard.pop_state();
  if (device_state.changed) {
    virtual_mouse.update_state(&device_state);
  }

  device_state = usb_mouse.pop_state();
  if (device_state.changed) {
    virtual_mouse.update_state(&device_state);
  }
}

static void sync_usb_joystick_state() {
  JoystickState device_state;
  JoystickLeds joy_leds = JoyLedNone;
  KeyboardLeds keyboard_leds = virtual_keyboard.get_led_state();

  // map keyboard LEDs to joystick LEDs
  if (keyboard_leds & KbLedCapsLock) {
    joy_leds = (JoystickLeds)(joy_leds | JoyLed1);
  }
  if (keyboard_leds & KbLedNumLock) {
    joy_leds = (JoystickLeds)(joy_leds | JoyLed2);
  }

  num_joys_connected = 0;

  for (uint8_t mapper_idx = 0; mapper_idx < num_joy_mappers; mapper_idx++) {
    uint8_t num_devices = joy_mappers[mapper_idx]->get_num_connected_devices();
    for (uint8_t device_idx = 0; device_idx < num_devices; device_idx++) {
      num_joys_connected += 1;
      bool is_player_1 = num_joys_connected < 2;
      device_state = joy_mappers[mapper_idx]->pop_state(device_idx);
      virtual_joystick.update_state(&device_state, is_player_1, setup_mode.swap_joy_axis_3_and_4);
      if (led_timer.getElapsedMillis() > LED_UPDATE_INTERVAL) {
        // in setup-mode, set LEDs of supporting joysticks
        if (setup_mode.in_setup_mode) {
          joy_mappers[mapper_idx]->set_led_state(joy_leds);
        } else {
          joy_mappers[mapper_idx]->set_led_state(JoyLedDefault);
        }
      }
    }
  }
}

static void sync_ps2_keyboard_state() {
  while (true) {
    KeyboardAction kb_action = virtual_keyboard.deq();
    if (kb_action.type == KbActionNone) {
      break;
    }
    ps2_keyboard.enq(kb_action);
  }

  if (!setup_mode.in_setup_mode) {
    virtual_keyboard.set_led_state(ps2_keyboard.get_led_state());
  }
}

static void sync_ps2_mouse_state() {
  if (mouse_state.changed) {
    ps2_mouse.update_state(&mouse_state);
  }
}

static void sync_gameport_state() {
  if (joy_state.changed) {
    gameport.setAxes(combine_axes(joy_state.axes[0], joy_state.axes[4]),
                     combine_axes(joy_state.axes[1], joy_state.axes[5]), joy_state.axes[2],
                     joy_state.axes[3]);
    gameport.setButtons(
        joy_state.buttons[0] | joy_state.buttons[6], joy_state.buttons[1] | joy_state.buttons[7],
        joy_state.buttons[2] | joy_state.buttons[8], joy_state.buttons[3] | joy_state.buttons[9]);
  }
}

static void handle_device_emulation() {
  MouseState new_mouse_state = virtual_mouse.pop_state();
  JoystickState new_joy_state = virtual_joystick.pop_state();

  // keep previous input states if not changed
  if (!new_mouse_state.changed) {
    mouse_state.changed = false;
    new_mouse_state = mouse_state;
  }
  if (!new_joy_state.changed) {
    joy_state.changed = false;
    new_joy_state = joy_state;
  }

  // push back virtual states
  virtual_mouse.update_state(&new_mouse_state);
  virtual_joystick.update_state(&new_joy_state, true, false);

  // handle all emulation modes
  switch (setup_mode.emu_mode) {
    case EmuModeJoyKeyb:
      joy_emulate_keyboard(&virtual_keyboard, &joy_state, &new_joy_state);
      break;
    case EmuModeJoyMouse:
      joy_emulate_mouse(&virtual_mouse, &new_joy_state, setup_mode.mouse_emu_speed);
      break;
    case EmuModeKeybJoy:
      keyboard_emulate_joy(&virtual_joystick, &virtual_keyboard);
      break;
    case EmuModeKeybMouse:
      keyboard_emulate_mouse(&virtual_mouse, &virtual_keyboard, setup_mode.mouse_emu_speed);
      break;
    case EmuModeMouseJoy:
      mouse_emulate_joy(&virtual_joystick, &new_mouse_state, setup_mode.mouse_emu_speed);
      break;
    default:
      break;
  }
}

static void update_debug_led_state() {
  // EXT_LED1 indicates PS/2 status
  digitalWrite(EXT_LED1_PIN,
               (ps2_keyboard_port.clock_enabled || ps2_keyboard_port.clock_inhibited ||
                ps2_mouse_port.clock_enabled || ps2_mouse_port.clock_inhibited)
                   ? LOW
                   : HIGH);

  // EXT_LED2 indicates button press
  bool button_pressed = false;
  for (uint8_t button = 0; button < JoystickState::NUM_BUTTONS; button++) {
    button_pressed |= joy_state.buttons[button];
  }
  if (button_pressed) {
    digitalWrite(EXT_LED2_PIN, LOW);
  } else {
    // or highest axis value
    uint8_t highest_axis_value = 0;
    for (uint8_t axis = 0; axis < JoystickState::NUM_AXES; axis++) {
      uint8_t axisValue = abs((int16_t)joy_state.axes[axis] - JOY_AXIS_CENTER);
      if (axisValue > highest_axis_value) {
        highest_axis_value = axisValue;
      }
    }
    digitalWrite(EXT_LED2_PIN, !soft_pwm.pwm(highest_axis_value >> 1));
  }
}

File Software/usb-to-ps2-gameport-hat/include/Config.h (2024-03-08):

#ifndef _CONFIG_H_
#define _CONFIG_H_

#include "KeyboardCodes.h"

#define Serial Serial1  // use pins D0/D1
#define SERIAL_SPEED 115200

// #define DEBUG_USB
#define DEBUG_PS2

#define PS2_1_DATA_PIN 2
#define PS2_1_CLOCK_PIN 3

#define PS2_2_DATA_PIN 17
#define PS2_2_CLOCK_PIN 16

#define JOY_BUTTON1_PIN 4
#define JOY_BUTTON2_PIN 5
#define JOY_BUTTON3_PIN 6
#define JOY_BUTTON4_PIN 7

#define EXT_LED1_PIN 8
#define EXT_LED2_PIN 9

#define POT1_CS_PIN 10

#define JOY_AXIS_TEST(axis, positive) \
  ((positive) ? ((axis) >= (JOY_AXIS_CENTER + 0x30)) : ((axis) <= (JOY_AXIS_CENTER - 0x30)))

#define JOY_AXIS_SET(axis, positive) \
  ((positive) ? ((axis) = (JOY_AXIS_CENTER + 0x50)) : ((axis) = (JOY_AXIS_CENTER - 0x50)))

#define LED_UPDATE_INTERVAL 10

#define SETUP_ENTER_DELAY 1250
#define SETUP_BLINK_WINDOW 1750

#define SWAP_JOY_AXIS_3_AND_4_DEFAULT false
#define MOUSE_EMU_SPEED_DEFAULT 2

#define NUM_KB_EMU_AXIS_MAPPINGS 12
#define NUM_KB_EMU_BTN_MAPPINGS 10

// clang-format off
static const KeyboardCodes KB_EMU_AXIS_MAPPINGS[NUM_KB_EMU_AXIS_MAPPINGS][2] = {
    {LeftArrow,     Keypad4Left},
    {RightArrow,    Keypad6Right},
    {UpArrow,       Keypad8Up},
    {DownArrow,     Keypad2Down},
    //
    {aA,            NoKey},
    {dD,            NoKey},
    {wW,            NoKey},
    {sS,            NoKey},
    //
    {LeftArrow,     Keypad4Left},
    {RightArrow,    Keypad6Right},
    {UpArrow,       Keypad8Up},
    {DownArrow,     Keypad2Down},
};
static const KeyboardCodes KB_EMU_BTN_MAPPINGS[NUM_KB_EMU_BTN_MAPPINGS][2] = {
    {LeftControl,   RightControl},
    {Space,         RightShift},
    {LeftAlt,       CapsLock},
    {LeftShift,     NoKey},
    //
    {PeriodGreater, NoKey},
    {CommaLess,     NoKey},
    //
    {UpArrow,       Keypad8Up},
    {DownArrow,     Keypad2Down},
    //
    {Escape,        NoKey},
    {Tab,           NoKey},
};
// clang-format on

#endif  // _CONFIG_H_

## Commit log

2020-02-22 fix issue with mouse scrollwheel in 5-button mode
2022-02-04 add schematic image
2022-02-04 update to KiCad 6
    [usb-to-ps2-gameport-hat-arduino-pro-mini.kicad_pcb, usb-to-ps2-gameport-hat-arduino-pro-mini.kicad_sch, usb-to-ps2-gameport-hat-arduino-pro-mini.sch]
2024-01-12 redesign setup mode, remove deadzone
    [Config.h, Logging.cpp, main.cpp]
2024-01-13 add keyboard bindings for setup mode
    [Logging.cpp, main.cpp]
2024-01-20 don't set led status on not connected devices
2024-01-20 fix inverted led state in logging
    [Logging.cpp]
2024-01-20 always signal inhibited state with LED1
2024-01-21 Initialize keyboard driver before HID universal
2024-01-21 Use updated drivers for is_connected check
2024-01-24 implement virtual devices
2024-01-24 support 8 virtual joy buttons
2024-01-26 implement device emulation modes
2024-01-26 speed up device initialization
2024-01-27 Use both ScrollLock and NumLock as LED2
2024-01-29 ensure correct order of MAKE/BREAK codes
    [main.cpp]
2024-02-05 Fix some joystick axis scaling issues
    [Config.h]
2024-02-05 fix various issues with emulation modes
    [Config.h, main.cpp]
2024-02-10 support Xbox 360 controller LEDs during setup mode
2024-02-13 Fix PS/2 resend behavior after inhibit
    [Config.h, Logging.cpp]
2024-02-14 fix some PS/2 timing issues
    [Config.h, main.cpp]
2024-02-17 fix inconsistent clock timing
    [main.cpp]
2024-02-19 always release data pin
2024-02-19 fix PS/2 device busy during multi-byte responses
2024-02-21 limit number of led flashes for XBOX Controller
2024-02-21 enable all buttons of secondary controllers
2024-02-29 properly align report buffer for keyboard leds
2024-03-01 limit update rate of all LEDs
2024-03-01 fix setup mode blinking issues
    [Config.h]
2024-03-08 fix mouse emulation modes + add speed setting
    [Config.h, main.cpp]
2024-03-08 @Ulfenknulfen: connect base of digi-pot with wiper
    [usb-to-ps2-gameport-hat-arduino-pro-mini-B_Cu.gbr, usb-to-ps2-gameport-hat-arduino-pro-mini-B_Mask.gbr, usb-to-ps2-gameport-hat-arduino-pro-mini-B_Paste.gbr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]
2024-03-09 prepare Release V1.4
    [usb-to-ps2-gameport-hat-arduino-pro-mini.kicad_pcb, usb-to-ps2-gameport-hat-arduino-pro-mini.kicad_sch]

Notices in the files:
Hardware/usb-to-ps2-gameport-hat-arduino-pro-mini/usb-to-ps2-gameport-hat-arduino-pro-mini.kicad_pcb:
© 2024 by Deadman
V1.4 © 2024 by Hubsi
